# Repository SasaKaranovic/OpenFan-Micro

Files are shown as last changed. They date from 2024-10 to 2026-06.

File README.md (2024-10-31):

# DIY OpenFAN Micro

## What is this project about?

DIY OpenFAN Micro (http://www.youtube.com/watch?v=TqN-tWI42gE "DIY OpenFAN Micro")

Above video shows the finished OpenFAN Micro, how it works and the motivation behind some of design decisions.

Some of the main features of the OpenFAN Micro are:

- Control a single 5V or 12V PWM fan over WiFi
- Fully stand-alone with built-in remote control
- Has a built-in USB bootloader for smooth firmware upgrade experience
- Web GUI to control and monitor fan. Accessible via web browser
- Built in Web API interface for integration, remote monitoring or remote control
- Built using simple off-the-shelf components to make it hacker/diy friendly
- Designed to be platform/OS agnostic and works on Windows, Linux and Mac
<br/><br/>

## Can I buy OpenFAN Micro

Yes you can. It's available on the [web shop](https://shop.sasakaranovic.com/products/openfan-micro).
<br/><br/>

## Can I build my own?

Yes you can. The above video explains the idea and how hardware and firmware works. It's recommended that you watch that first.

Hardware, Firmware and Software build instructions and source files are available in this repository.
<br/><br/>

## Where can I find more documentation

Project documentation and quick-start guide is available on [docs.sasakaranovic.com](https://docs.sasakaranovic.com/openfan_micro/).

<br/><br/>

## What platforms are supported?

OpenFAN Micro is designed to be platform agnostic. This means you can use it on Windows, Linux and Mac.
You can control it manually via built in Web UI.
Or automate control using built in Web API and you automation/scripting of choice.

<br><br>

## Useful links

Blog page: https://sasakaranovic.com/projects/openfan-controller/

YouTube video: http://www.youtube.com/watch?v=TqN-tWI42gE

<br/><br/>

#### Sasa Karanovic

<a href="https://sasakaranovic.com/" target="_blank" title="Sasa Karanovic Home Page"> Home Page</a> &nbsp;&middot;&nbsp;
<a href="https://youtube.com/c/sasakaranovic" target="_blank" title="Sasa Karanovic on YouTube"> YouTube</a> &nbsp;&middot;&nbsp;
<a href="https://github.com/sasakaranovic" target="_blank" title="Sasa Karanovic on GitHub"> GitHub</a> &nbsp;&middot;&nbsp;
<a href="https://twitter.com/_sasakaranovic_" target="_blank" title="Sasa Karanovic on Twitter"> Twitter</a> &nbsp;&middot;&nbsp;
<a href="https://instagram.com/_sasakaranovic_" target="_blank" title="Sasa Karanovic on Instagram"> Instagram</a> &nbsp;&middot;&nbsp;
<a href="https://github.com/sponsors/SasaKaranovic" target="_blank" title="Sponsor on GitHub"> Sponsor on GitHub</a>

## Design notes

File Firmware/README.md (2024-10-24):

# How to build firmware

For our firmware development, we are going to use Arduino. Mainly because it's user friendly, easy to use and most hobbyists are familiar with it or have already used it. While we could build the same or even more efficient firmware using C and ESP-IDF, we are going to stick with Arduino and hope that this allows the project to be
more friendly and easier to use/modify by wider DIY/hacker community.

# Do I really need to build the firmware?

If you don not need any firmware modifications and you are using the official [OpenFAN Micro](https://shop.sasakaranovic.com/products/openfan-micro), then you do not have to. You can just use the web flasher to update your board to the latest firmware version.
Latest version of the firmware is available online and can be loaded using the [web flasher](https://docs.sasakaranovic.com/openfan_micro/firmware_upgrade/).
Please keep in mind that this firmware version is for the official OpenFAN Micro that is available on the [web shop](https://shop.sasakaranovic.com/products/openfan-micro).

## How can I build/compile firmware?

Arduino has many third party libraries that you can use and also build firmware for many different boards.
However, depending for which board you are building firmware and also which libraries your project (sketch) uses, you might need to manually install them or download them trough board/library manager.

While above mentioned solution works fine, it can lead to issues like installing the "wrong/different" version of the library, different board files, "wrong/different" build/upload tools and so on.
On top of that, since board files and libraries are shared, we could install a library or a board file while working on another project that breaks our current project.
Hopefully you can see why this is not so great for open-source open-hardware project where we want everyone to be able to easily checkout a repository and hit the ground running without spending hours setting up and debugging what library or board files are missing.

Luckily we can automate/avoid this by using a build system like PlatformIO. So below we will have two ways of building the firmware, one will be "easy" by leveraging PlatformiIO build system, and the other one will be a manual one by using Arduino IDE and manually searching and downloading all the board/library files.

## - The super easy way - Compile and upload using PlatformIO build system  - 

### 1. Install PlatformIO

Installing PlatformIO CLI is pretty straight-forward and also well documented for Windows, Linux and MacOS.
You will need to follow few steps and get PlatformIO CLI installed, detailed tutorial can be found at https://platformio.org/install/cli
Make sure to install [PlatformIO Core](https://docs.platformio.org/en/latest//core/installation.html#installation-methods 'https://docs.platformio.org/en/latest//core/installation.html#installation-methods') and allso that it is available trough [shell](https://docs.platformio.org/en/latest//core/installation.html#piocore-install-shell-commands 'PlatformIO Core - Install Shell Commands').

### 2. Build firmware

Open shell/command-prompt and navigate to 'Firmware/platformio' folder.
1. Compile the firmware by typing `pio run`, PlatformIO will download all the required board files and libraries and finally compile the firmware.
2. Upload the firmware with `pio run --target upload --upload-port <COM-PORT>`. Make sure to replace `<COM-PORT>` with your ESP32's COM port (ie COM1 or /dev/ttyACM0)

[<- Go back to repository root](../README.md)

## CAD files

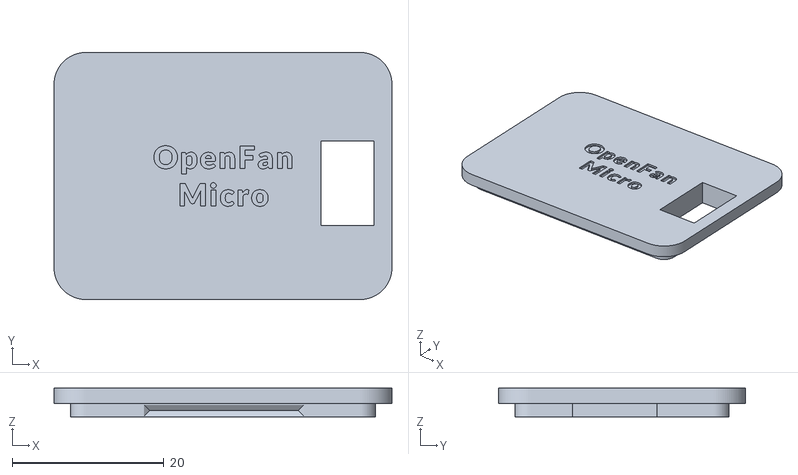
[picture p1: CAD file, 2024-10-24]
Enclosure/Enclosure_Top.stl
44.6 x 32.6 x 3.80

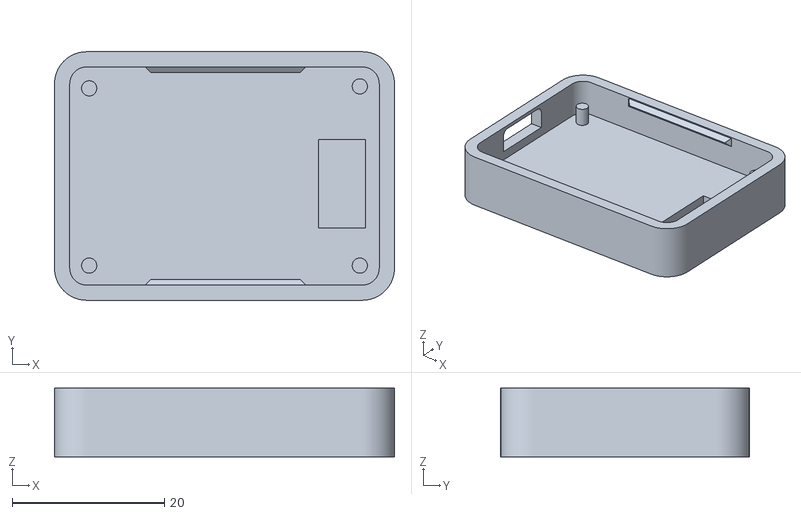
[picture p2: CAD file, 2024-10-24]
Enclosure/Enclosure_Bottom.stl
44.6 x 32.6 x 9.00

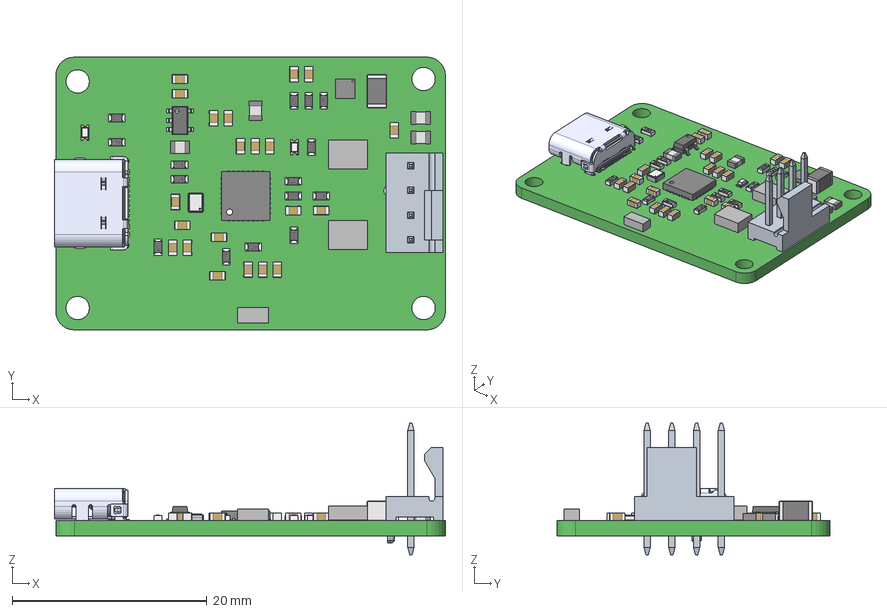
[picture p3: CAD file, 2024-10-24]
Enclosure/OpenFAN_Micro.step
40.1 x 28.0 x 13.5 mm
SW3DPS-CAPACITOR 0805-DEFAULT x 4
User Library-RES_1609-0603 x 15
User Library-LED_0603_WS_Pocket002 x 2
User Library-LED_0603_WS_Pad004 x 2
User Library-LED_0603_WS_Fillet x 2
User Library-LED_0603_WS_Pocket001 x 2
User Library-LED_0603_WS_Pad x 2
User Library-CAPC1608X09 x 21
User Library-NT2016SA-END4910A-48MHZ Crystal (NDK)
Thermal_Shape
Extruded x 3
User Library-SOT23-5-2
USB4105-GF-A--3DModel-STEP-46669
MIC2290YML-TR

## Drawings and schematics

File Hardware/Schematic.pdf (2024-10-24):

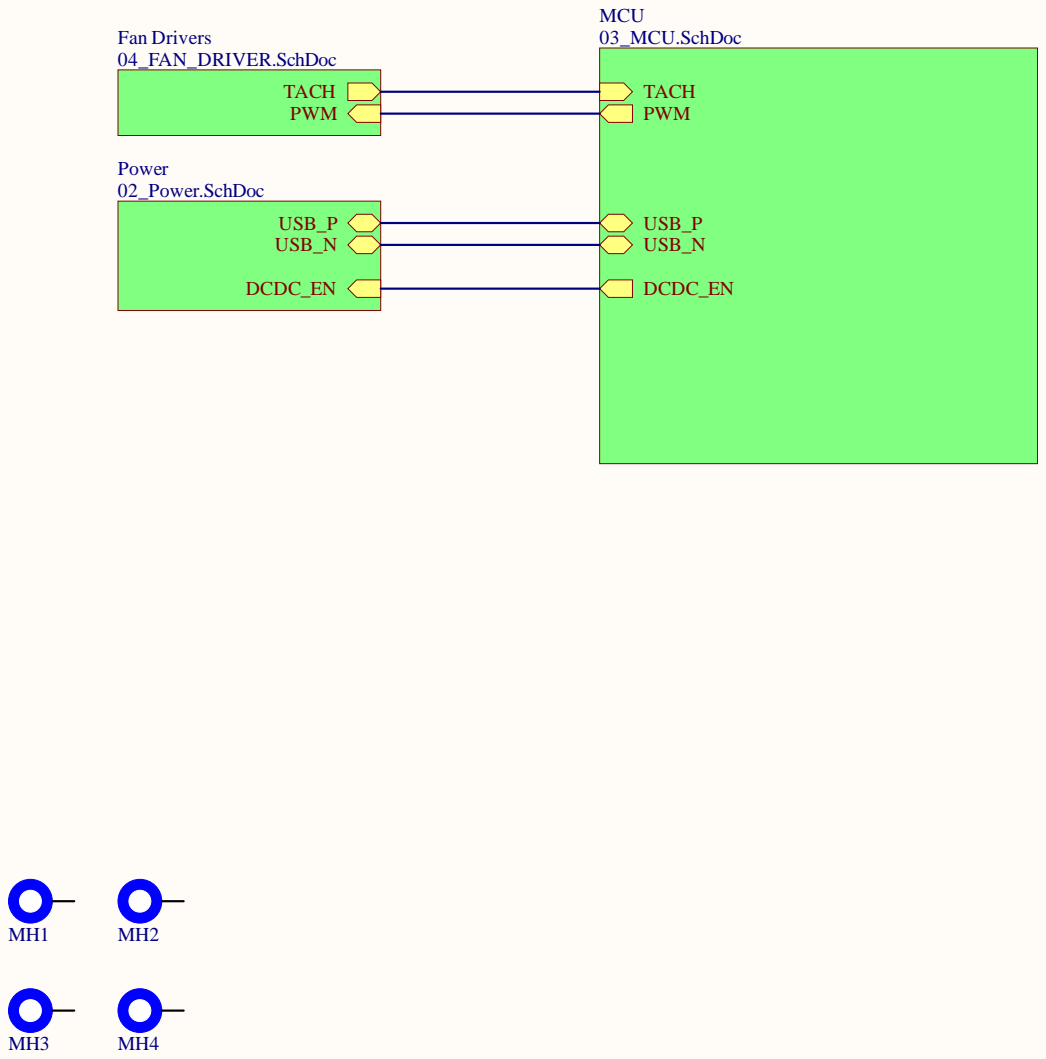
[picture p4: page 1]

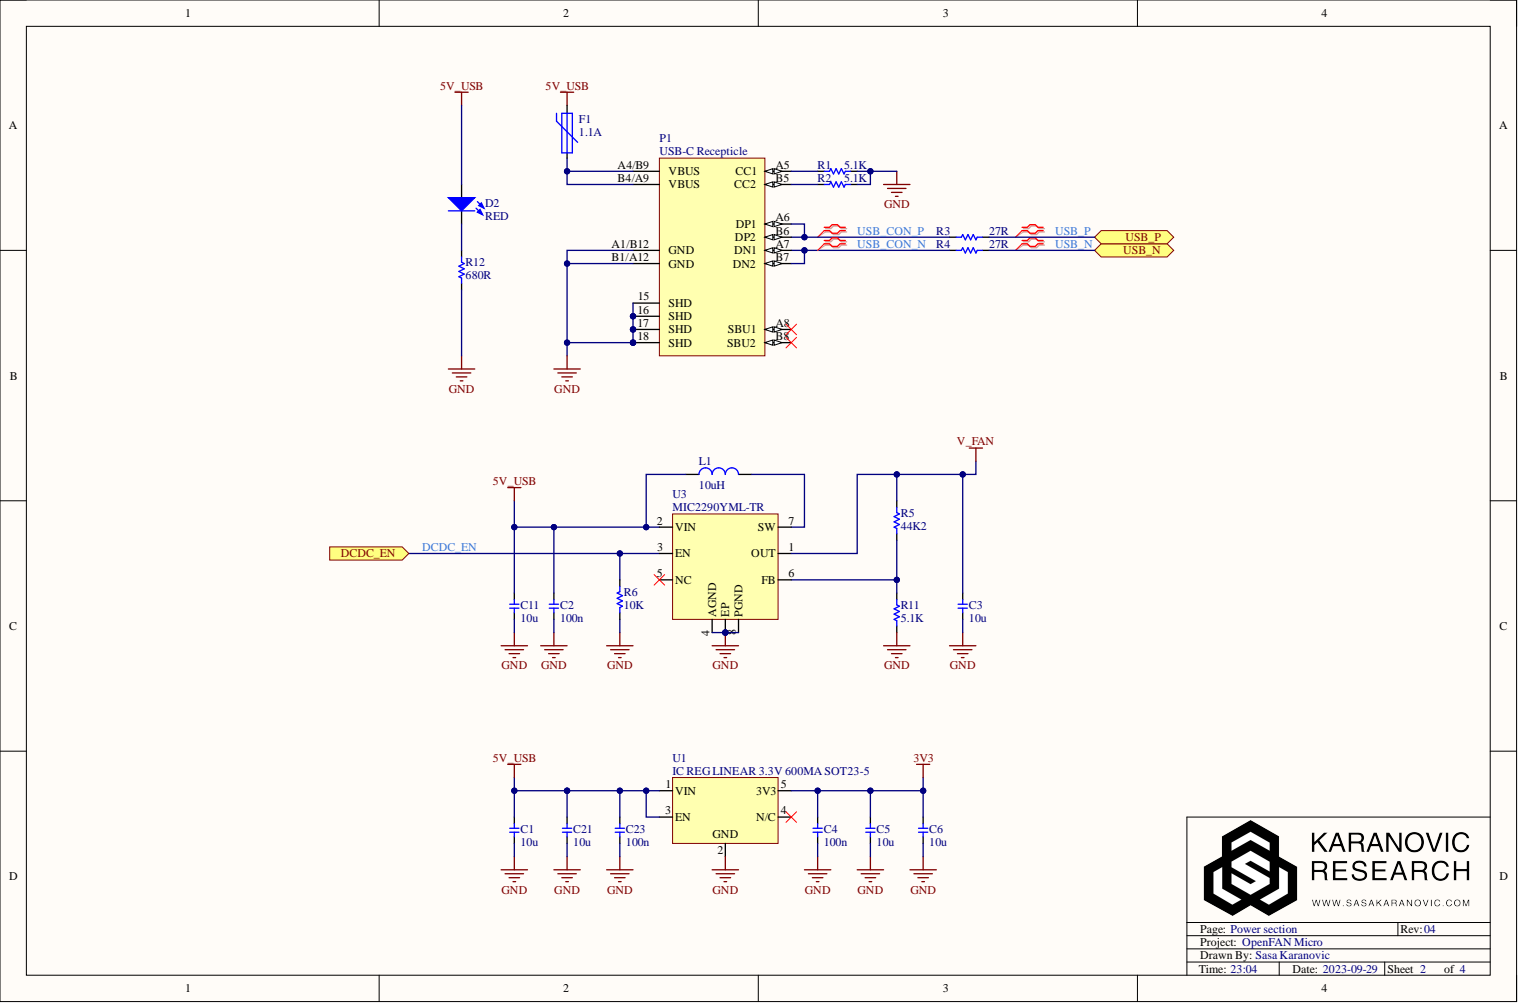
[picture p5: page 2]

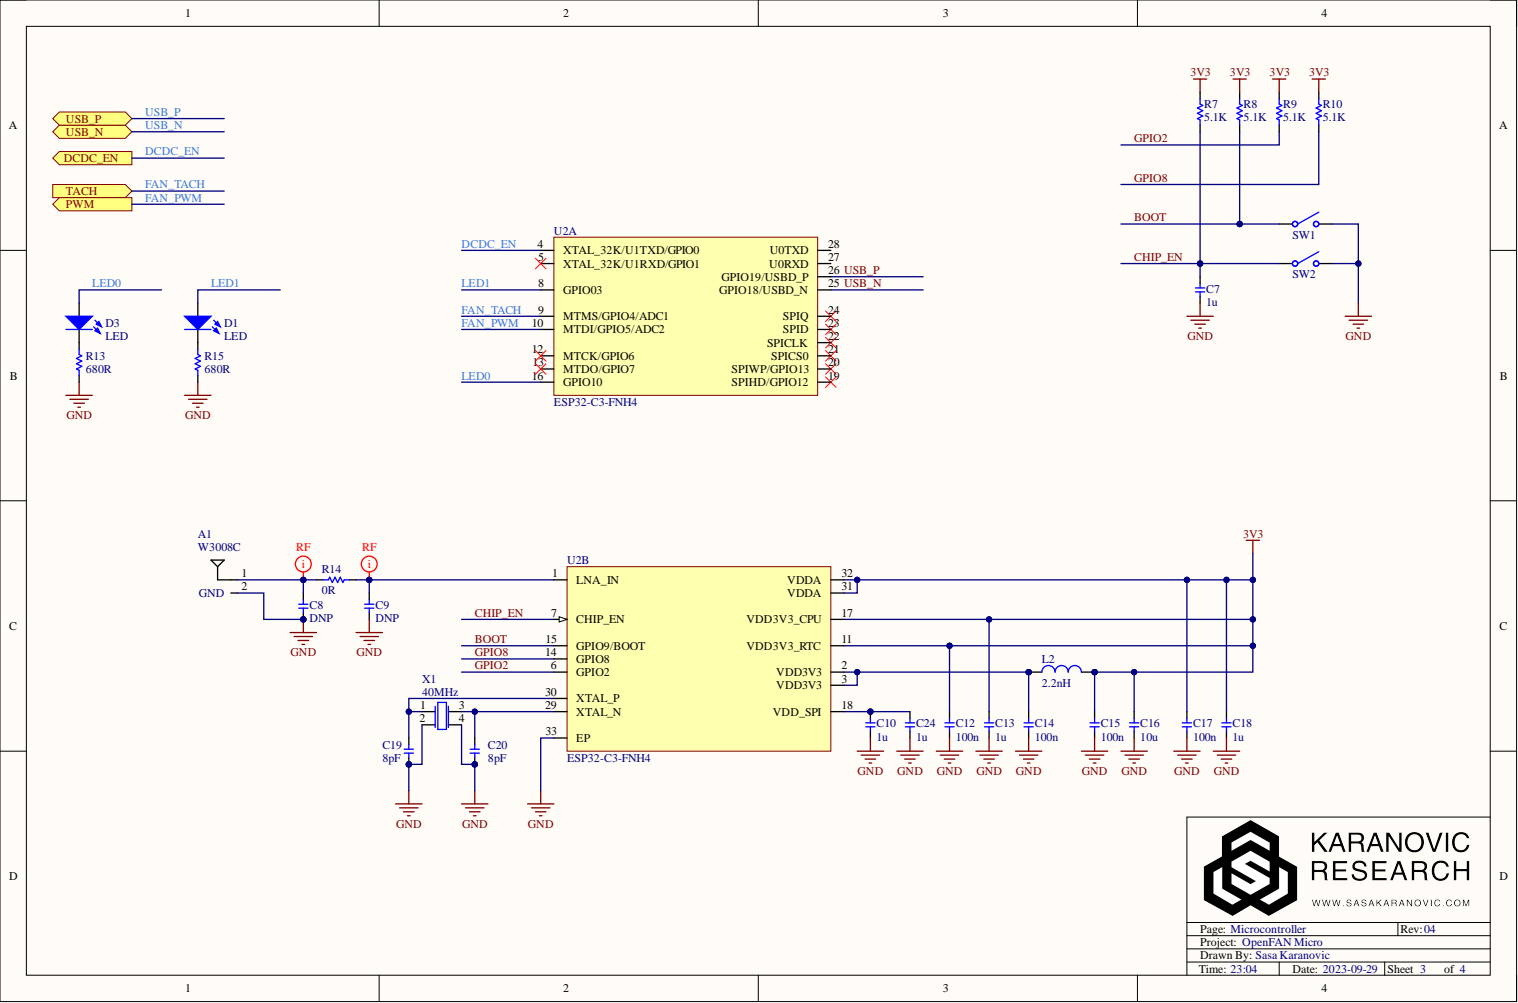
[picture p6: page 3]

GPIO2

GPIO8

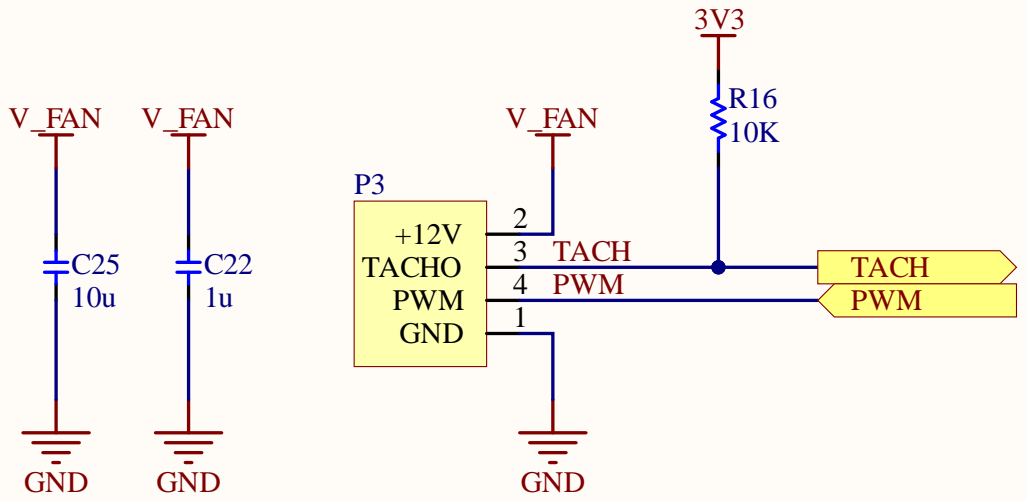
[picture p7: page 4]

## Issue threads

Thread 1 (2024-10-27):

Feature request: Fan ramp-up on power up before applying last PWM value

SasaKaranovic, 2024-10-27:
On power up, run the fan at maximum speed to allow it to ramp-up before re-applying previous PWM value.

For example if the previous fan PWM value is 10%. Applying such low value on power-up might not spin up the fan.
However if the fan is ramped-up first and then 10% PWM is applied, the fan should continue to spin.

The ramp-up period could be ~5 seconds and during this period we should monitor the RPM to see if the fan has actually spun up or to report an error to the end user.

SasaKaranovic, 2024-10-31:
Added in `v2024-10-27`

Closed 2024-10-31.

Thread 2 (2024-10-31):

Switching between 5V and 12V fan supply

DeepCoreSystem, 2024-10-31:
Hi there!

I found your project through hackster.io because I was looking for some ideas about an ESPHome fan controller.

I opened the schematic and PCB in KiCad, but I can't figure out how you perform the switching between 5V and 12V for the fan supply. I see that you use GPIO 0 to control the enable pin of the DC/DC boost IC.

But even with the datasheet of the MIC2290, I don't understand how disabling the DC/DC converter should deliver 5V to the fan. A low on the DC/DC Enable pin should disable the boost converter, thus delivering 0 V on its output, isn't it?

DeepCoreSystem, 2024-11-01:
I'll answer my question myself ... In general, any DC/DC boost converter has a leakage path where Vin will be present on Vout, even when the enable pin is pulled low.
For extensive information, see this application note by Texas Instruments:
[Boost Behaviors During Shutdown - Pass Through, Bypass or True Disconnection](https://www.ti.com/lit/pdf/SLVAFO4)

SasaKaranovic, 2024-11-02:
Hey @DeepCoreSystem

If you look at the MIC2290 internal block diagram, you will see that SW and OUT have a Schottky diode between them.
Some regulators will have this built-in internally, but it's also common to have this as an external component.
The EN pin only disables the regulator (switching), however we still have a path from VUSB to OUT via the L1 and built in Schottky diode.

p.s. Personally I think that "leakage" term is often used to describe some undesired/negative/parasitic effect. In this case this path exists by design and it is very much desired. :)

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

Closed 2024-11-01.

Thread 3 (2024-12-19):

Enclosure opening fit

EdeVriesCVE, 2024-12-19:
The holes to allow the fan and power cables aren't centered in the model. The top has the opening for the fan cable, which is 9.7mm and 11.6mm from edge of part to edge of hole.

the pcb has these connectors center, the fan cable has 8.75mm to the edge of the board.

SasaKaranovic, 2025-01-03:
Thanks @EdeVriesCVE !

Can you please send an image of the issue just to get a better picture of what you are describing?
Are you not able to connect the USB and/or FAN cable?

Closed 2025-05-15.

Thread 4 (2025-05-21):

Security Issue: Unwanted switch to AP mode if Wi-Fi connection fails

eber42, 2025-05-21:
On startup, if the OpenFan can not connect to WiFi, it will switch to the wide open AP mode. I think this is a big security (& safety) risk because anybody in range can connect it to any network and mess with settings.

For example if you have a power outage, the OpenFan and your WiFi hotspot will both restart, which leads to the above issue (it occurred to me this morning).

Possible solutions include :
- do not bring up AP mode if the device has already been initialised
- protect AP mode (e.g. password)

SasaKaranovic, 2025-05-22:
Thanks for opening the issue @eber42 .

Please feel free to modify the behaviour (see https://github.com/SasaKaranovic/OpenFan-Micro/blob/master/Firmware/src/main.ino#L78) and submit a pull request if you feel like sharing.

OpenFAN Micro will try to connect to the WiFi network four times, if this fails it will fall back to "config" state.
This is a compromise in case you move the device from one place to another (or use as portable controller), change WiFi network etc.

`- do not bring up AP mode if the device has already been initialised`
The device has no way of knowing if your WiFi network has changed, device got moved out-of-range/weak-signal and if this is just a temporary or permanent situation. So it could be waiting forever without the end-user knowing what is wrong.

`- protect AP mode (e.g. password)`
This is security through obscurity, at best. You would need to know (hard-code) that password ahead of time in order to connect, so if it's a "shared password", not a solution.

I don't necessarily agree that this is a "big security & safety risk", especially considering the exposure and how it works.

But luckily there are multiple ways of addressing this if you consider it unwanted behaviour. On of the benefits of open-source open-hardware projects is that you can customize it to your use-case.

p.s. Regardless of what people/authors claim, it's safe to assume that "S" in "IoT" stands for security. 😉

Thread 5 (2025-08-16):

[Feature Request] Is it possible to control the fan directly via USB?

Metus88, 2025-08-16:
I like your project, but I would like to know if it is possible to control the board (and also the fan connected to it) via USB cable. I like the idea of using Wi-Fi, but in some cases (such as when the fan is connected to the PC via USB), it would be more reliable to control it with a script on a Linux/Debian mini PC. If the Wi-Fi network goes down or other issues occur, it is more reliable to control it via cable.
My question: is it theoretically possible to do that with your OpenFan Micro hardware?

Metus88, 2025-08-17:
Good to know it’s possible! I’m not able to edit the firmware, but I’m glad the hardware doesn’t have this limitation. I read the comment section you linked, and my concern is exactly that there could be communication issues and it might fail to automatically control the fan. My plan is to use it to control the CPU PWM fan of a mini PC that doesn’t have BIOS settings to change the temperature setpoint (and there isn't fan controller avaible via software), and this use case is pretty delicate.

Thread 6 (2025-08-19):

[Question] Altium file: Are the USB connector and footprint really compatible?

Metus88, 2025-08-19:
Opening your Altium file with the online viewer on the Altium website, I see this information for the USB connector:
Footprint: [GCT USB4105-GF-A](https://www.mouser.it/datasheet/2/837/Global_Connector_Technology_usb4105-3106202.pdf)
Part: [USB-TYPE-C-019](https://www.lcsc.com/datasheet/C2927039.pdf)

Out of curiosity, I checked online and they look very similar, but I’m not really sure they are compatible. Can you confirm that there is no problem using the footprint of a different component? Are the footprints of USB-TYPE-C-019 and GCT USB4105-GF-A compatible?

Thanks for the clarification.

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

Closed 2025-09-05.

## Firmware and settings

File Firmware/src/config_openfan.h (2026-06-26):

#ifndef __CONFIG_OPEN_FAN_CFG_H_INC__
#define __CONFIG_OPEN_FAN_CFG_H_INC__

#define BOARD_REVISION          2
#define DEFAULT_HOSTNAME        "MyOpenFan\0"
#define DEFAULT_HOSTNAME_LEN    10
#define NAME_MAX_LEN            64
#define MAX_CUSTOM_NAME         12
#define MIN_CUSTOM_NAME         3
#define PIN_FAN_PWM             5
#define PIN_FAN_TACH            4
#define PWM_CH_FAN              0
#define PIN_LDO_EN              0
#define PIN_LDO_LED             3
#define PIN_LED_ACT             10
#define FAN_INT_PER_REV         2   // Number of TACH interrupts per single rotation
#define FAN_PWM_SAVE_PERIOD     10000
#define FAN_PWM_FREQ            25000
#define FAN_PWM_RESOLUTION      8
#define LED_BLINK_PERIOD        500
#define FAN_RPM_PAUSE_PERIOD    500
#define FAN_RPM_SAMPLE_PERIOD   500
#define FAN_STARTUP_BOOST_TIME  5000
#define FAN_STARTUP_BOOST_PWM   100
#define WIFI_TX_POWER_LEVEL     WIFI_POWER_8_5dBm
#define WIFI_CONN_CHECK_TICK    30000
#define MAX_LEN_MAC_BYTES       6
#define MAX_LEN_MAC_STRING      16
#define MAX_LEN_DEVICE_NAME     128
#define OPENFAN_USE_USB_COMM    1
#define ENABLE_WIFI             1

// Persistent data storage
typedef struct eeprom_data
{
    bool enable_12v;
    bool enable_act_led;
    uint8_t last_percent;
    uint8_t impulse_per_rev;
    char deviceName[NAME_MAX_LEN+1];
    uint8_t valid;
} eeprom_data_t;

#endif

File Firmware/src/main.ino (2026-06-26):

#include <ESPmDNS.h>
#include <EEPROM.h>
#include <WiFiManager.h>
#include <CRC.h>
#include "ESPAsyncWebServer.h"
#include "WiFi.h"
#include "version.h"
#include "config_openfan.h"

WiFiManager wifiManager;
eeprom_data_t eepromData;
AsyncWebServer server(80);

volatile int WiFi_status = WL_IDLE_STATUS;
String deviceHostname = "sk-openfan-micro";
String mdnsName = "MyOpenFan";
char MACString[MAX_LEN_MAC_STRING] = {0};
uint32_t nLed_Tick = 0;
uint32_t nRPM_Tick = 0;
uint32_t nWiFi_Tick = 0;
volatile uint32_t fan_int_cnt = 0;
uint32_t fan_millis_start = 0;
uint32_t fan_millis_end = 0;
uint32_t fan_rpm = 0;
uint32_t nFanSave_Tick = 0;
uint8_t u8FanPercent = 0;
bool bRPM_counting = false;
bool bStartUpBoost = true;
uint32_t nStartUpBoost_Timeout = 0;

#if OPENFAN_USE_USB_COMM
#include "serial_comm.h"
uint8_t pTxBuffer[COMM_TX_BUFFER_LEN] = {0};
uint32_t nTxBufferLen = 1;
uint8_t pRxBuffer[COMM_RX_ASCII_BUFFER_LEN] = {0};
uint32_t nRxBufferLen = 0;
uint8_t pPackage[COMM_RX_HEX_BUFFER_LEN] = {0};
uint32_t nPackageLen = 0;
volatile bool bRxStarted = false;
volatile bool bRxComplete = false;
#endif

void setup()
{
    Serial.begin(115200);
    Serial.setDebugOutput(true);
    delay(1000);
    Serial.println("OpenFAN - Micro");
    Serial.println("Version: " + String(VERSION_MAJOR) + "-" + String(VERSION_MINOR) + "-" + String(VERSION_PATCH) );

    eeprom_init();
    eeprom_load();
#if ENABLE_WIFI
    set_device_mdns_name();
    WiFi.setHostname(mdnsName.c_str());

    WiFi.mode(WIFI_STA);
    WiFi.setTxPower(WIFI_TX_POWER_LEVEL);

    int txPower = WiFi.getTxPower();
    Serial.print("TX power: ");
    Serial.println(txPower);

    delay(1000);
#endif
    // Setup GPIO
    pinMode(PIN_LED_ACT, OUTPUT);
    digitalWrite(PIN_LED_ACT, HIGH);

    pinMode(PIN_LDO_EN, OUTPUT);
    digitalWrite(PIN_LDO_EN, LOW);

    pinMode(PIN_LDO_LED, OUTPUT);

    if (eepromData.enable_12v)
    {
        Serial.println("Enabling 12V DC-DC");
        fan_enable_12V(true);
    }
    else
    {
        Serial.println("Keeping 12V DC-DC disabled");
        fan_enable_12V(false);
    }

    fan_setup();
    set_pwm(eepromData.last_percent);

#if ENABLE_WIFI
    bool res;
    res = wifiManager.autoConnect("SK-OpenFAN");

    wifiManager.setHostname(mdnsName.c_str());
    wifiManager.setConnectRetries(4);

    if(!res) {
        Serial.println("Failed to connect or hit timeout");
        ESP.restart();
    }
    else {
        Serial.println("Connected.");
    }

    Serial.print("WiFi IP: ");
    Serial.println(WiFi.localIP());

    get_mac_string(MACString, MAX_LEN_MAC_STRING);

    if (!MDNS.begin(mdnsName.c_str()))
    {
        Serial.println("Error starting mDNS");
    }
    else
    {
        Serial.println((String) "mDNS http://" + mdnsName + ".local");

        // Advertise services
        MDNS.addService("http", "tcp", 80);
    }

    Serial.print("Starting WebServer...");
    WebServer_Setup();
    Serial.println("done.");

    Serial.print("WiFi IP: ");
    Serial.println(WiFi.localIP());
#endif
    // Debug message to signal we are initialized and entering loop
    Serial.println("Ready to go.");
    digitalWrite(PIN_LED_ACT, LOW);

    // Enable fan PWM boost
    bStartUpBoost = true;
    nStartUpBoost_Timeout = millis() + FAN_STARTUP_BOOST_TIME;
    Serial.print("Turning ON fan starup boost for ");
    Serial.print(FAN_STARTUP_BOOST_TIME);
    Serial.println(" miliseconds");
    set_pwm(FAN_STARTUP_BOOST_PWM);

#if OPENFAN_USE_USB_COMM
    host_comm_rearm();
#endif
}


void loop()
{
    if (eepromData.enable_act_led)
    {
        if (nLed_Tick <= millis())
        {
            digitalWrite(PIN_LED_ACT, !digitalRead(PIN_LED_ACT));
            nLed_Tick = millis() + LED_BLINK_PERIOD;
        }
    }

    // Update RPM
    fan_tick();

#if ENABLE_WIFI
    // Check WiFi status
    wifi_check();
#endif

#if OPENFAN_USE_USB_COMM
    // Handle serial comm over USB
    serial_comm_tick();
#endif
}


void wifi_check(void)
{
    wl_status_t WiFiStatus;

    if (nWiFi_Tick <= millis())
    {
        WiFiStatus = WiFi.status();
        if ((WiFiStatus != WL_CONNECTED))
        {
            Serial.println("WiFi is disconnected... Reconnecting to WiFi...");
            if (WiFi.disconnect())
            {
                Serial.println("Disconnected. Attempting reconnect...");
            }
            else
            {
                Serial.println("Failed to disconnect within 1000 ms...");
            }

            WiFi.reconnect();
        }

        nWiFi_Tick = millis() + WIFI_CONN_CHECK_TICK;
    }
}

bool get_mac_bytes(char *mac, uint8_t nLen)
{
    if(mac == NULL || nLen < 6)
    {
        return false;
    }

    for(int i=0; i<6; i++)
    {
        mac[i] = ((ESP.getEfuseMac() >> (i*8)) & 0xff);
    }
    return true;
}

bool get_mac_string(char *string, uint8_t nLen)
{
    if(string == NULL)
    {
        return false;
    }

    char uChipId[MAX_LEN_MAC_BYTES] = {0};
    char strDeviceMAC[16] = {0};

    if(!get_mac_bytes(&uChipId[0], MAX_LEN_MAC_BYTES))
    {
        return false;
    }

    snprintf(string, nLen, "%02X%02X%02X%02X%02X%02X",
            uChipId[0], uChipId[1], uChipId[2], uChipId[3], uChipId[4], uChipId[5]);

    return true;
}


void set_device_mdns_name(void)
{
    char uChipId[MAX_LEN_MAC_BYTES] = {0};
    char strName[128] = {0};

    // Check if EEPROM name is valid
    if (
        (strnlen(eepromData.deviceName, MAX_CUSTOM_NAME)<1) ||
        (!is_valid_name((const uint8_t *)&eepromData.deviceName, MAX_CUSTOM_NAME))
       )
    {
        Serial.print("EEPROM Name Length: ");
        Serial.println(strlen(eepromData.deviceName));

        Serial.print("Invalid EEPROM name: ");
        Serial.println(String(eepromData.deviceName));
        Serial.println("Resetting EEPROM name.");
        eeprom_initialize_name();
    }

    get_mac_bytes(uChipId, MAX_LEN_MAC_BYTES);

    Serial.print("EEPROM name: ");
    Serial.println(String(eepromData.deviceName));

    snprintf(strName, 128, "uOpenFan-%s", eepromData.deviceName);
    mdnsName = String(strName);
}

bool is_valid_name(const uint8_t *pData, uint8_t nLen)
{
    for(uint8_t i=0; i<nLen; i++)
    {
        if ( ((pData[i]<'0') && (pData[i]>'9')) &&
             ((pData[i]<'A') && (pData[i]>'Z')) &&
             ((pData[i]<'a') && (pData[i]>'z')) )
        {
            return false;
        }
    }

    return true;
}

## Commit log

2025-12-18 Adding more verbose printout for WiFi disconnect/reconnect.
2025-12-18 Adding fw version serial printout during boot.
2025-12-18 Moving WiFi.reconnect() outside if/else so we call it even if previous WiFi.disconnect() call fails.
    [main.ino]
2025-12-18 Refactoring eeprom_load() as per issue #10
    [eeprom.ino, main.ino]
2025-12-18 Removing .onNotFound() handler as per issue #9
    [web.ino]
2026-01-28 Fixing a typo preventing proper device name (re)set.
    [web.ino]
2026-06-26 Adding ifdef for wifi check. Removing unsupported command (RPM). Calculating PWM percent value before passing to set_fan.
2026-09-28 Fixing name/set API typo.
    [web.ino]
2026-09-28 Adding buttons for common fan presets (0%, 25%, 50%, 75%, 100%)
2026-09-28 Remove faked fan data for fans 2-10. Update GET_RPM to check FAN index. Update FAN_SET_ALL_PWM to work properly.
